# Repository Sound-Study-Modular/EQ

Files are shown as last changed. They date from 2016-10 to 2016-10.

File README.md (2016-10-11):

# EQ

Learn SMD soldering by building two channels of the kind of tone controls you’d find on an old hifi.

Top channel = Baxandall EQ, treble/bass cut/boost
Bottom channel = Tilt EQ

No voltage control, but just enough range to push sounds into distortion.

Works well in a feedback loop.

Download the Bill of Materials

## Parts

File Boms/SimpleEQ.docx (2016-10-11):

Resistors:

QTY | Value | Ref. | Mouser Part #
2 | 220‎‎Ω | R13, R14 | 667-ERJ-6ENF2200V
2 | 1.8kΩ | R5, R10 | 667-ERJ-6ENF1801V
2 | 2.2kΩ | R8, R11 | 667-ERJ-6ENF2201V
2 | 6.8kΩ | R9, R12 | 667-ERJ-6ENF6801V
1 | 9.1kΩ | R7 | 667-ERJ-6ENF9101V
4 | 10kΩ | R1, R2, R3, R4 | 667-ERJ-6ENF1002V
1 | 22kΩ | R6 | 667-ERJ-6ENF2202V

TOTAL: 14

Diodes:

QTY | Value | Ref. | Mouser Part #
2 | 1N5819 | D1, D2 | 621-1N5819HW-F

TOTAL: 2t

Capacitors:

QTY | Value | Ref. | Mouser Part #
2 | 22pF Ceramic | C4, C6 | 81-GRM21A5C2E220JW1D
1 | 4.7nF Ceramic | C2 | 81-GRM2165C1H472GA01
2 | 33nF Ceramic | C3, C5 | 81-GRM40X333J50D
5 | 100nF Ceramic | C1, C7, C8, C11, C12 | 81-GRM40X104K50
2 | 47uF Electrolytic | C9, C10 | 667-EEE-FK1V470P

TOTAL: 12

Integrated Circuits:

QTY | Value | Ref. | Mouser Part #
2 | NE5532 op amp | IC1, IC2 | 595-NE5532D

TOTAL: 2

Potentiometers:

QTY | Value | Ref. | Mouser Part #
3 | 10kΩ Vert Mount | BASS, TILT, TREBLE | Synthrotek

TOTAL: 3

Jacks:

QTY | Value | Ref. | Mouser Part #
4 | PJ301M-12 Inline PCB Mount Mono 3.5mm | BAX_IN, BAX_OUT, TILT_IN, TILT_OUT | Synthrotek

TOTAL: 4

Other:

QTY | Value | Ref. | Mouser Part #
2 | 200mA Resettable Fuse | F1, F2 | 652-MF-PSMF020X-2
3 | White Davies Clone Knobs | BASS, TILT, TREBLE | Synthrotek2
1 | 5x2 Unshrouded Header | POWER | 649-67996-410HLF
2 | 2.5 x 6mm Rack Screws | N/A | Synthrotek
2 | 3.0 x 6mm Rack Screws | N/A | Synthrotek
1 | PCB/Panel set | N/A | Synthrotek
1 | 10 to 16 pin Power Cable | N/A | Synthrotek

TOTAL: 9

Page *Note: all parts are SMD 0805 package except Jacks and Pots

Simple EQ Bill of Materials Updated: 09.14.2016

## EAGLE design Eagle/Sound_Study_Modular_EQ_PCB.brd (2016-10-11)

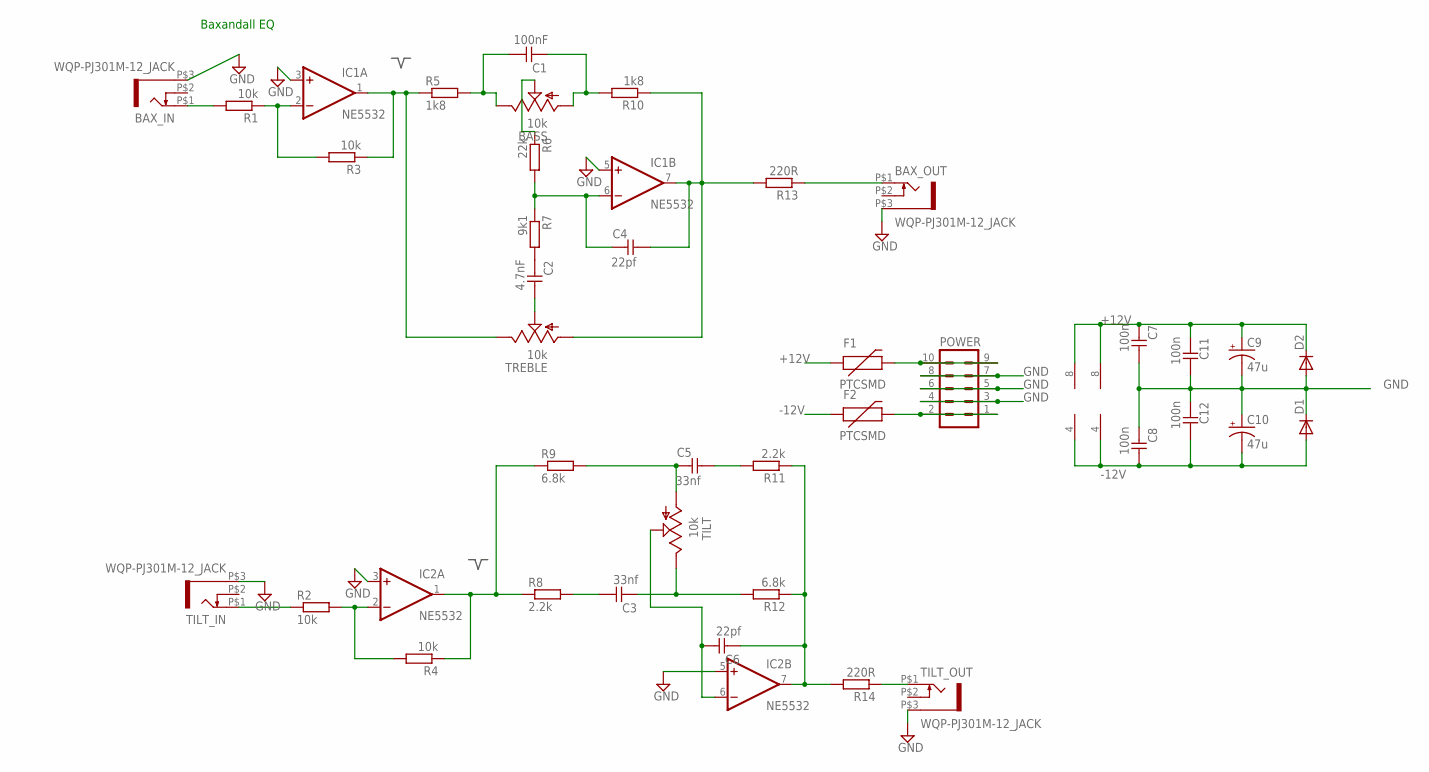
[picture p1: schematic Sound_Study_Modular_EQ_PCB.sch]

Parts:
BASS: 10k; EVUF
BAX_IN: WQP-PJ301M-12_JACK
BAX_OUT: WQP-PJ301M-12_JACK
C1: 100nF; R0805
C2: 4.7nF; R0805
C3, C5: 33nf; R0805
C4, C6: 22pf; R0805
C7, C8, C11, C12: 100n; R0805
C9, C10: 47u; PANASONIC_D
D1, D2: DIODE-SOD123; SOD123
F1, F2: PTCSMD; PTC-1206
IC1, IC2: NE5532; SO08
POWER: 10_PIN_HEADER; MA05-2
R1, R2, R3, R4: 10k; R0805
R5, R10: 1k8; R0805
R6: 22k; R0805
R7: 9k1; R0805
R8, R11: 2.2k; R0805
R9, R12: 6.8k; R0805
R13, R14: 220R; R0805
TILT: 10k; EVUF
TILT_IN: WQP-PJ301M-12_JACK
TILT_OUT: WQP-PJ301M-12_JACK
TREBLE: 10k; EVUF

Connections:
+12V: C7.2, C9.+, C11.2, D2.C, F1.1, IC1.8 (V+), IC2.8 (V+)
-12V: C8.1, C10.-, C12.1, D1.A, F2.1, IC1.4 (V-), IC2.4 (V-)
BAX1: C4.1, IC1.7 (OUT), R10.1, R13.2, TREBLE.1 (A)
BAX$1: BAX_IN.P$1 (2), R1.2
BAX$2: BAX_OUT.P$1 (2), R13.1
BAX$24: IC1.2 (-IN), R1.1, R3.2
BAX$26: C2.1, TREBLE.2 (S)
BAX$27: BASS.3 (E), C1.1, R5.2
BAX$28: BASS.1 (A), C1.2, R10.2
BAX$29: BASS.2 (S), R6.1
BAX$31: IC1.1 (OUT), R3.1, R5.1, TREBLE.3 (E)
BAX$32: C4.2, IC1.6 (-IN), R6.2, R7.1
GND: BAX_IN.P$3 (1), BAX_OUT.P$3 (1), C7.1, C8.2, C9.-, C10.+, C11.1, C12.2, D1.C, D2.A, IC1.3 (+IN), IC1.5 (+IN), IC2.3 (+IN), IC2.5 (+IN), POWER.3, POWER.4, POWER.5, POWER.6, POWER.7, POWER.8, TILT_IN.P$3 (1), TILT_OUT.P$3 (1)
unnamed: IC2.2 (-IN), R2.2, R4.2
unnamed: IC2.1 (OUT), R4.1, R8.1, R9.1
unnamed: R14.1, TILT_OUT.P$1 (2)
unnamed: R2.1, TILT_IN.P$1 (2)
unnamed: F1.2, POWER.9, POWER.10
unnamed: F2.2, POWER.1, POWER.2
unnamed: C3.1, R8.2
unnamed: C3.2, R12.2, TILT.3 (E)
unnamed: C5.2, R9.2, TILT.1 (A)
unnamed: C5.1, R11.2
unnamed: C6.1, IC2.6 (-IN), TILT.2 (S)
unnamed: C2.2, R7.2
TILT_OUT: C6.2, IC2.7 (OUT), R11.1, R12.1, R14.2

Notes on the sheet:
Baxandall EQ

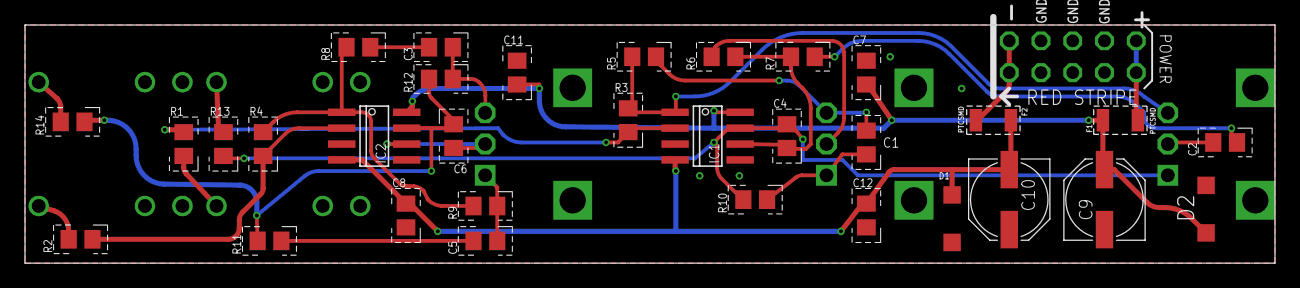
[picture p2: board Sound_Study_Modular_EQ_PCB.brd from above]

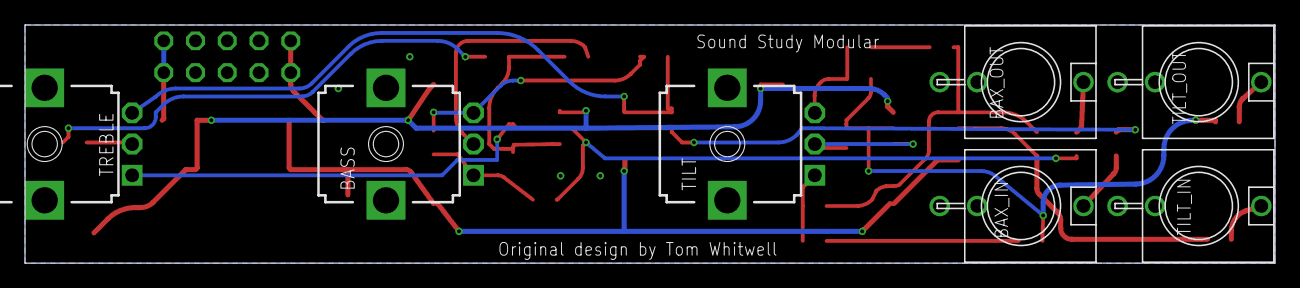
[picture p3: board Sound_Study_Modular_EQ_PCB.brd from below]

Board: 4 copper layers, 100.0 x 19.1 mm, 40 parts (7 on the bottom side), 26 nets.

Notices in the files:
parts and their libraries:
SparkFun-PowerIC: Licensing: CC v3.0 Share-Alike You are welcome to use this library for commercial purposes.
